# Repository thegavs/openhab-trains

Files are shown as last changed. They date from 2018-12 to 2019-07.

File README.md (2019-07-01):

# openhab-trains
Openhab-trains.  Combining the power of home automation systems and cheap arduinos to provide open source modules for running model trains.

Designed for Garden railways where dcc running over tracks proves problematic but will work with smaller scales.  The wifi modules have been 
tested at over 200 feet (60 metres) both inside and outside.
All modules are designed to run off 12v stepped down to 5v on board.   Most modules could also be modified to run on battery power.

Using the home automation system allows for complex rules to be set up, allowing electronic interlocking to be used for route setting. 

The Aim for this project is for people to be able to build simple cheap modules to control their layout and develop and add other modules 
to expand the system.

The core of the system is Openhab2 running on a Raspberry Pi. 

https://www.openhab.org/

Openhab is open source and free to use.

For ease of install I suggest using Openhabian.

https://www.openhab.org/docs/installation/openhabian.html

The modules are arduinos

https://www.arduino.cc/

I suggest using the nodemcu exp8266 or esp32 modules as they are inexpensive and powerful.

Video of first two modules in action.

https://youtu.be/3NVWC1UaGtM

**Modules published.**

Levers - reads the position of levers and transmits value to server.

signal - moves two semaphore signals.

points - moves 3 points.

relay - activates 2 relays

**Modules in development.**

ground signal - for two ground signals.

Brushless - allows control of brushless motors

**Install guides**

A guide to installing openhab server is in the openhab/install directory.

**Arduino modules**

Each module has its own directory with the code, wiring diagrams and component lists.

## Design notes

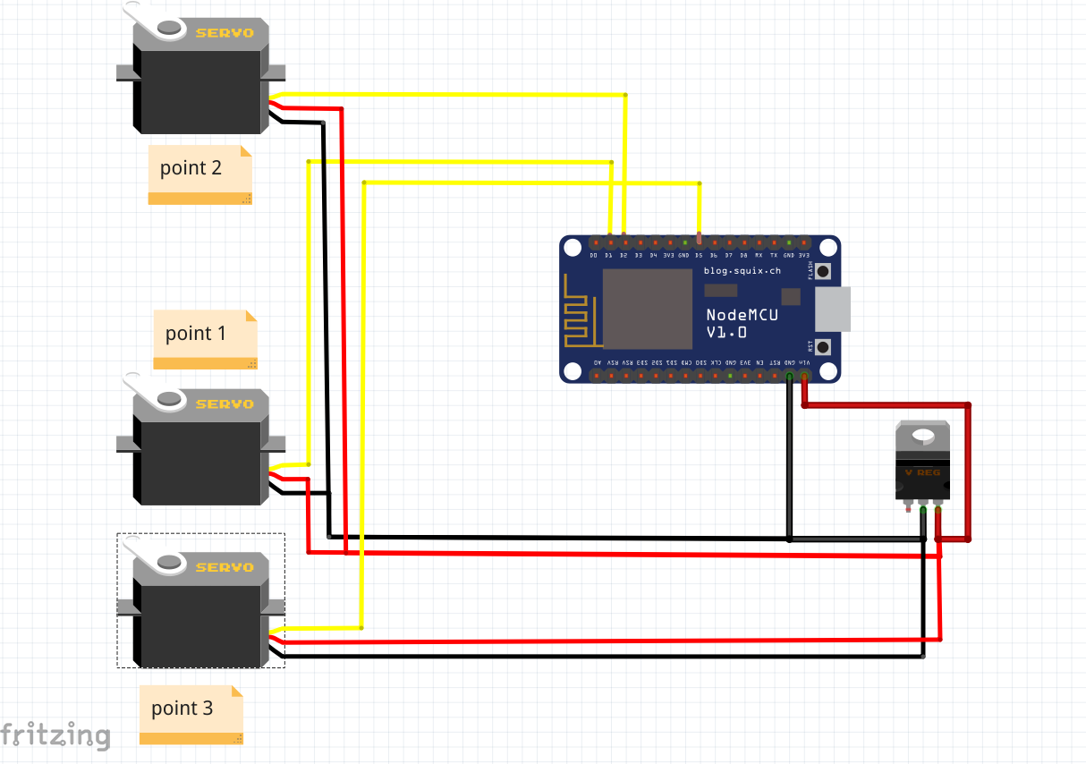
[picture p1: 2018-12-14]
arduino modules/points/points schematic.png

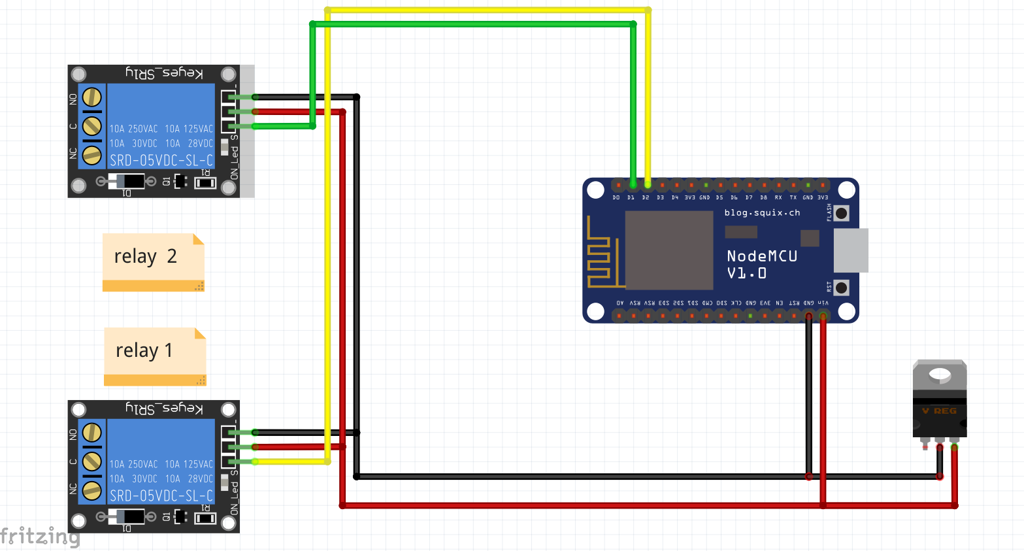
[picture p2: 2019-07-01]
arduino modules/relay/relay schematic.png

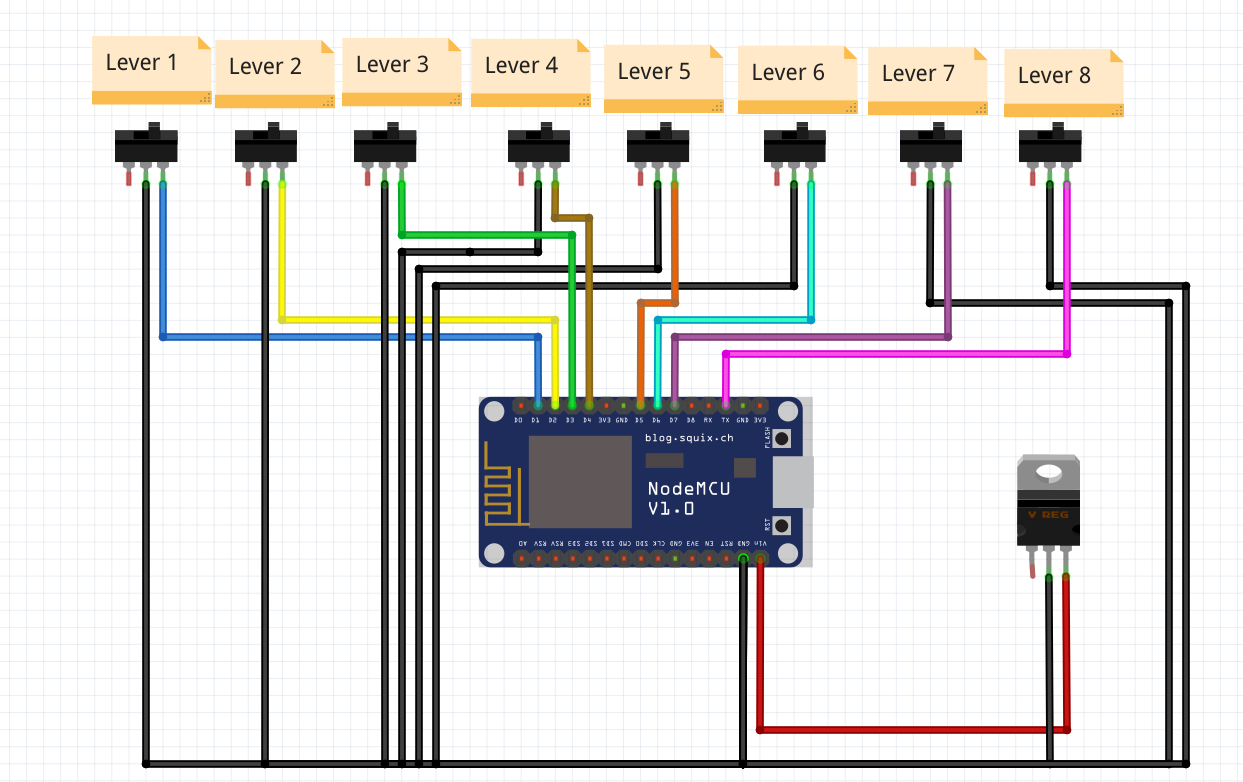
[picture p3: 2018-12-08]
arduino modules/signal levers/levers/levers_schematic.png

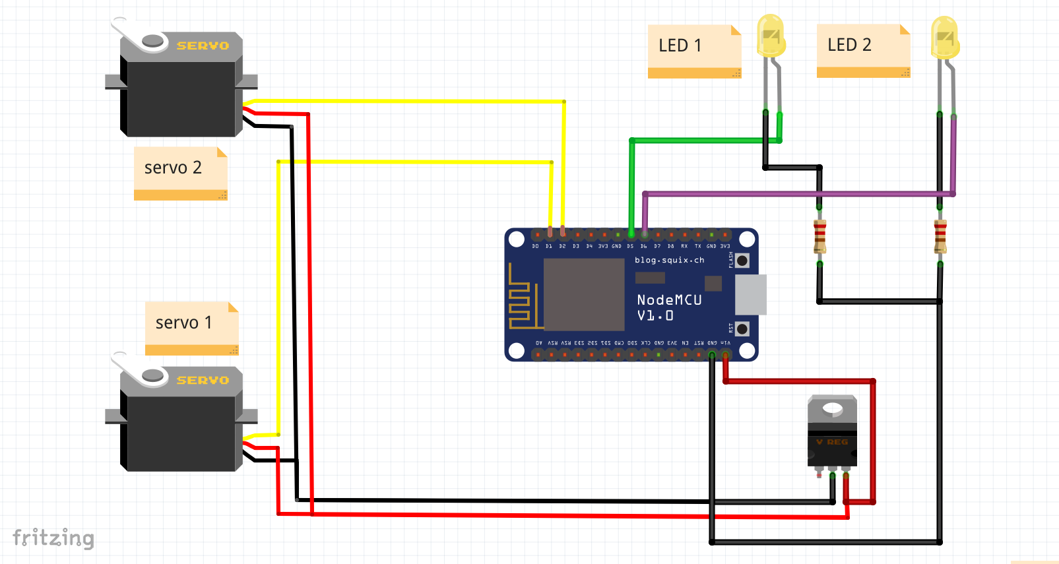
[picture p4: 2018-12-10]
arduino modules/signals/signal/signal schematic.png

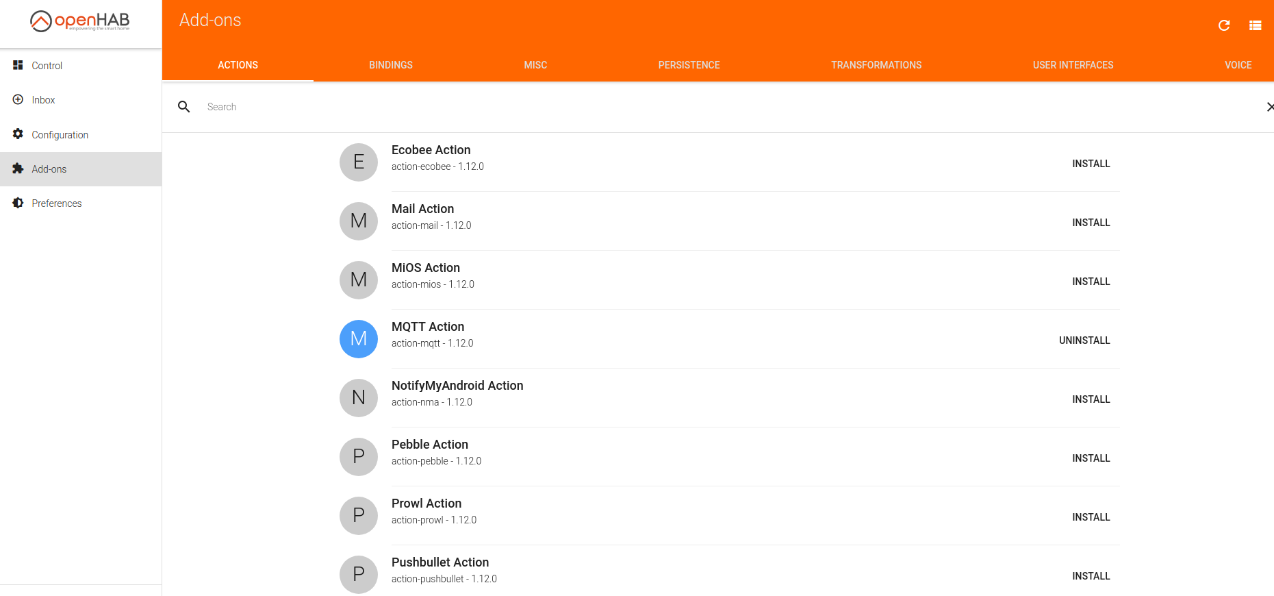
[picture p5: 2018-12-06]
arduino modules/signal levers/levers/MQTT action.png

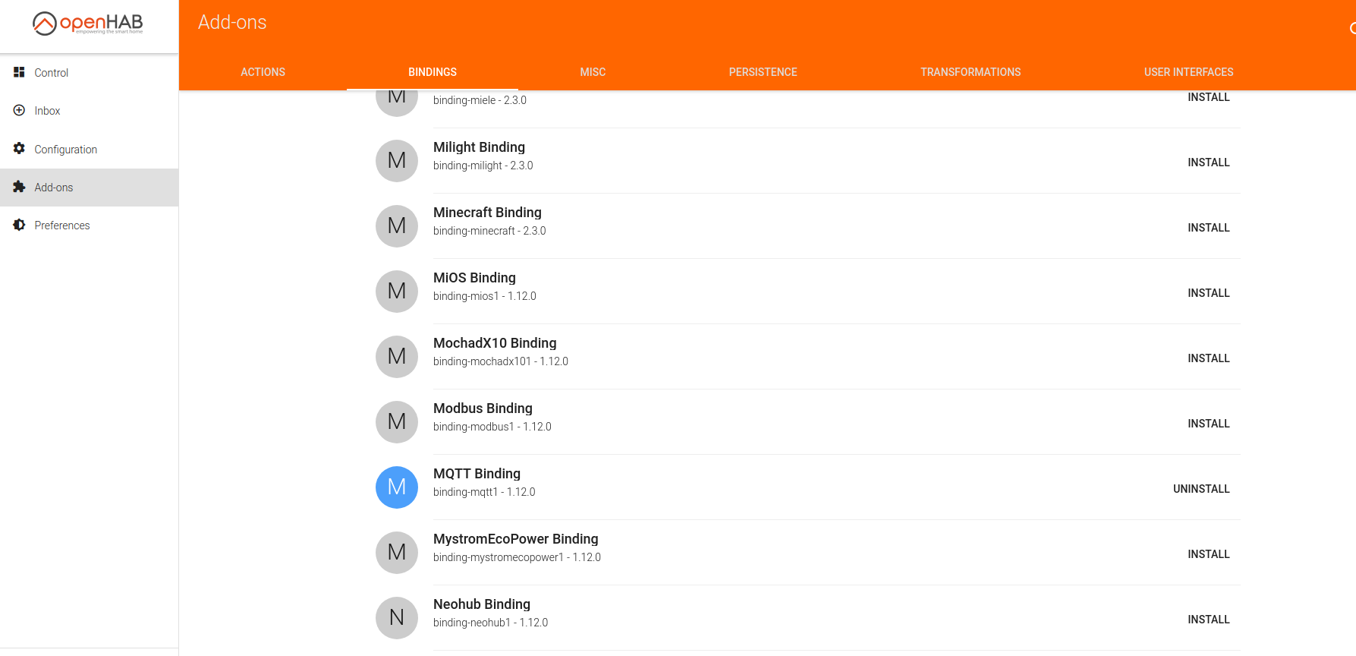
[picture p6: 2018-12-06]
arduino modules/signal levers/levers/MQTT binding.png

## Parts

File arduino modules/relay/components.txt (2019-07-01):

levers

This is a list of suggested components with links and costs.  I have no affiliation with the links other than a happy customer.

nodemcu (arduino)
https://www.ebay.co.uk/itm/NodeMcu-Lua-V3-ESP8266-CH340G-ESP-12E-WIFI-Lua-Internet-Development-Board-Module-/291968023031
cost from £2.36

voltage regulator 5v
https://www.bitsbox.co.uk/index.php?main_page=product_info&cPath=140_171&products_id=1306
cost £0.37

stripboard (will make multipule modules)
https://www.bitsbox.co.uk/index.php?main_page=product_info&cPath=238_244&products_id=1858
£2.80

assortied wire (will make multipule modules)
https://www.bitsbox.co.uk/index.php?main_page=product_info&cPath=200_201&products_id=2167
£1.88

15 way connector x 2
https://www.bitsbox.co.uk/index.php?main_page=product_info&cPath=225_230&products_id=2879
£0.68

5v relay x2
https://www.ebay.co.uk/itm/5V-12V-or-24V-1-2-4-8-16-Channel-Relay-Module-Arduino-PI-ARM-AVR-DSP-PIC-/262722739443
£2.75

Total cost around £15 the wire and strip board will do several modules cost ignoring these is around £6.16 per module.

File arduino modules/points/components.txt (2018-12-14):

levers

This is a list of suggested components with links and costs.  I have no affiliation with the links other than a happy customer.

nodemcu (arduino)
https://www.ebay.co.uk/itm/NodeMcu-Lua-V3-ESP8266-CH340G-ESP-12E-WIFI-Lua-Internet-Development-Board-Module-/291968023031
cost from £2.36

voltage regulator 5v
https://www.bitsbox.co.uk/index.php?main_page=product_info&cPath=140_171&products_id=1306
cost £0.37

stripboard (will make multipule modules)
https://www.bitsbox.co.uk/index.php?main_page=product_info&cPath=238_244&products_id=1858
£2.80

3 way JYK connectors female x 3
https://www.bitsbox.co.uk/index.php?main_page=product_info&cPath=225_339&products_id=2796
£0.27

3 way JYK connectors male x 3
https://www.bitsbox.co.uk/index.php?main_page=product_info&cPath=225_339&products_id=2797
0.50

crimp connectors x10
https://www.bitsbox.co.uk/index.php?main_page=product_info&cPath=225_339&products_id=2793
£0.70

assortied wire (will make multipule modules)
https://www.bitsbox.co.uk/index.php?main_page=product_info&cPath=200_201&products_id=2167
£1.88

15 way connector x 2
https://www.bitsbox.co.uk/index.php?main_page=product_info&cPath=225_230&products_id=2879
£0.68

Servos x3
https://www.ebay.co.uk/
£7.77

Total cost around £17 the wire and strip board will do several modules cost ignoring these is around £12.65 per module.

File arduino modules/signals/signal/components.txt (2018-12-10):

levers

This is a list of suggested components with links and costs.  I have no affiliation with the links other than a happy customer.

nodemcu (arduino)
https://www.ebay.co.uk/itm/NodeMcu-Lua-V3-ESP8266-CH340G-ESP-12E-WIFI-Lua-Internet-Development-Board-Module-/291968023031
cost from £2.36

voltage regulator 5v
https://www.bitsbox.co.uk/index.php?main_page=product_info&cPath=140_171&products_id=1306
cost £0.37

stripboard (will make multipule modules)
https://www.bitsbox.co.uk/index.php?main_page=product_info&cPath=238_244&products_id=1858
£2.80

connectors male x2
https://www.bitsbox.co.uk/index.php?main_page=product_info&cPath=225_339&products_id=2794
£0.18

connectors female x 2
https://www.bitsbox.co.uk/index.php?main_page=product_info&cPath=225_339&products_id=2792
£0.14

3 way JYK connectors female x 2
https://www.bitsbox.co.uk/index.php?main_page=product_info&cPath=225_339&products_id=2796
£0.18

3 way JYK connectors male x 2
https://www.bitsbox.co.uk/index.php?main_page=product_info&cPath=225_339&products_id=2797
0.32

crimp connectors x10
https://www.bitsbox.co.uk/index.php?main_page=product_info&cPath=225_339&products_id=2793
£0.70

assortied wire (will make multipule modules)
https://www.bitsbox.co.uk/index.php?main_page=product_info&cPath=200_201&products_id=2167
£1.88

15 way connector x 2
https://www.bitsbox.co.uk/index.php?main_page=product_info&cPath=225_230&products_id=2879
£0.68

LED x2
https://www.bitsbox.co.uk/index.php?main_page=product_info&cPath=172_176&products_id=1340
£0.20

220ohm resistor x 2
https://www.bitsbox.co.uk/index.php?main_page=product_info&cPath=83_84_85&products_id=437
£0.14

Servos x2
https://www.ebay.co.uk/itm/Tower-Pro-SG-90-SG90-9g-Micro-Servo-For-Car-Helicopter-Plane-Boat-New-UK-Seller/201515155582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
£5.18

Total cost around £15 the wire and strip board will do several modules cost ignoring these is around £10.45 per module.

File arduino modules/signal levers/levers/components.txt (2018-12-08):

levers

This is a list of suggested components with links and costs.  I have no affiliation with the links other than a happy customer.

nodemcu (arduino)
https://www.ebay.co.uk/itm/NodeMcu-Lua-V3-ESP8266-CH340G-ESP-12E-WIFI-Lua-Internet-Development-Board-Module-/291968023031
cost from £2.36

voltage regulator 5v
https://www.bitsbox.co.uk/index.php?main_page=product_info&cPath=140_171&products_id=1306
cost £0.37

stripboard (will make multipule modules)
https://www.bitsbox.co.uk/index.php?main_page=product_info&cPath=238_244&products_id=1858
£2.80

connectors male x8
https://www.bitsbox.co.uk/index.php?main_page=product_info&cPath=225_339&products_id=2794
£0.72

connectors female x 8
https://www.bitsbox.co.uk/index.php?main_page=product_info&cPath=225_339&products_id=2792
£0.56

crimp connectors x16
https://www.bitsbox.co.uk/index.php?main_page=product_info&cPath=225_339&products_id=2793
£0.64

assortied wire (will make multipule modules)
https://www.bitsbox.co.uk/index.php?main_page=product_info&cPath=200_201&products_id=2167
£1.88

15 way connector x 2
https://www.bitsbox.co.uk/index.php?main_page=product_info&cPath=225_230&products_id=2879
£0.68

Total cost around £10 the wire and strip board will do several modules cost ignoring these is around £5.33 per lever module.

These costs do not account for switches or levers as these will be personal preferences.

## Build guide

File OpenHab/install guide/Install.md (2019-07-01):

# Openhab install guide.

##**Introduction**

Openhab is an open source home automation system that can run on different hardware platforms.
I recommend using a [Raspberry Pi](https://www.raspberrypi.org/products/raspberry-pi-3-model-b-plus/).

These are simple but powerful tiny computers, that dont take much power.  

More information on openhab is available [here](https://www.openhab.org/) 

Below is a guide to install OpenHab on a raspberry pi.   All links are correct as of 21 dec 2018.

##**Openhabian**

[Openhabian](https://www.openhab.org/docs/installation/openhabian.html)  is a port of OpenHab that is designed for ease of installation on a Raspberry Pi.  Below is a step by step guide to installation.  
If links are out of date please contact me.

**1. Download Openhabian**

The Github page for Openhabian will have the latests releases [here](https://github.com/openhab/openhabian/releases) 

The latest RaspBerry Pi image is [here](https://bintray.com/openhab/bin/download_file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) This is a large download at
circa 255Mb.  The downloaded file needs to be written to the micro SD card that came with the Raspberry Pi.
As it is an image of a disk it needs to be extracted then written, various tools exist to do this I suggest using etcher.

**2. Etcher**

Etcher is a tool to write disk images to SD cards, it is available [here](https://www.balena.io/etcher/).
Once Etcher is installed simply select the image file you downloaded, then select the drive containing the 
Micro SD card then press Flash.

This will extract the files and check them.

**3. Update wifi details**

If you plan to use wifi on the raspberry pi you will need to update the wifi credentials.  If not move to step 4.

Access the first SD card partition from the file explorer of your choice (e.g. Windows file explorer)
Open the file openhabian.conf in a text editor
Uncomment and fill in wifi_ssid="My Wi-Fi SSID" and wifi_psk="password123"

This adds your wifi details

**4. Start install.**

Unmount the micro SD card then insert into the Pi.    The system is designed to run "headless" i.e no monitor, but a monitor can be plugged into the HDMI port.

Put the micro SD card into the pi and power on, if you skipped step 3 plug in the network cable first.   Grab a beer/tea and come back in an hour.

Note that if the wifi fails try the following.

Full steps below:

Flash fresh openHABian image to SD card (openhabianpi-raspbian-201804031720-gitdba76f6-crc9e93c3eb.img.xz)
Boot 3B+ from flashed SD, observe network error
Login on local shell using openhabian/openhabian
sudo raspi-config - set Network SSID, Passphrase, and WiFi Country
reboot

** 5. Connect to server**

In a web browser connect to http://ipaddress:8080 the first time you connect you should see a screen asking you to select "simple standard expert demo"  select the expert option then you should see various screens.

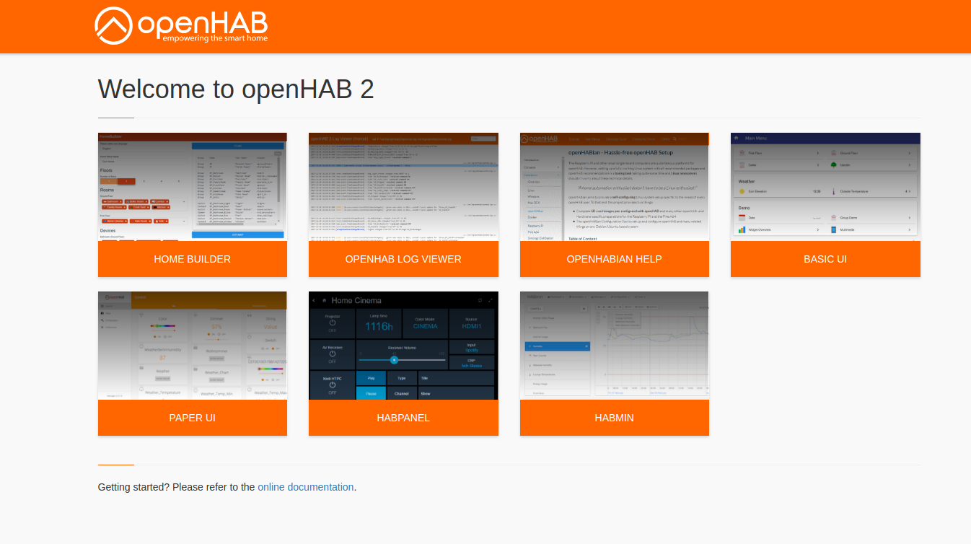
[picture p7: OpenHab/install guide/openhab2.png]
start screen


PaperUI is used to configure the server.

connecting to http://ipaddress:9001 will show you the log file.

Using filemanger on your PC you should be able to connect to a network drive with a username and password
of openhabian  this will allow you to change the configuration files.

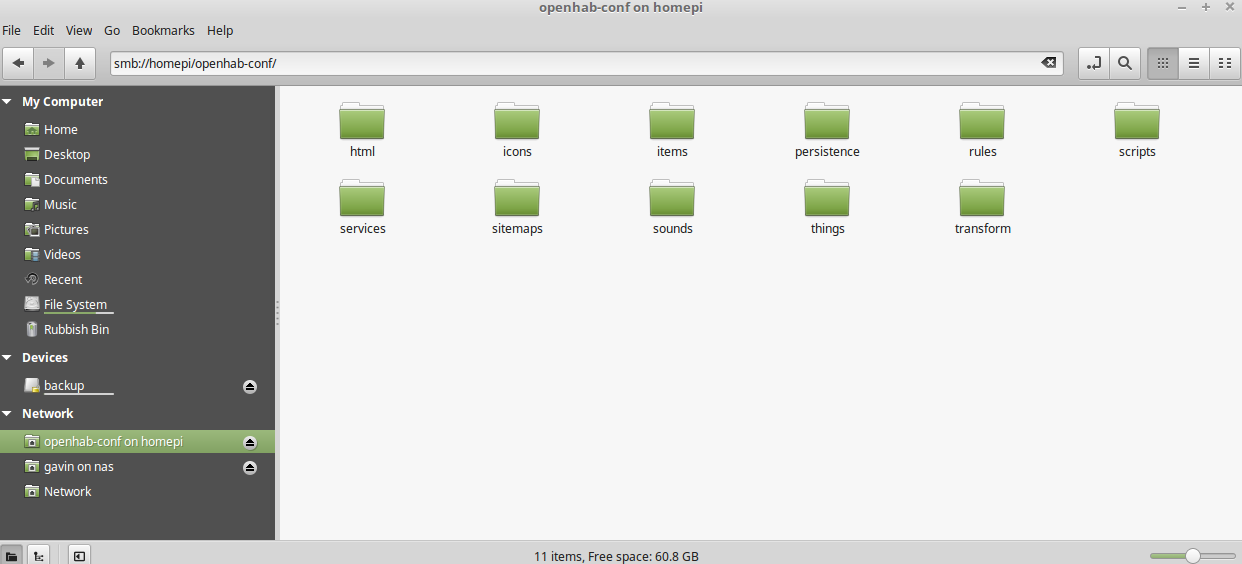
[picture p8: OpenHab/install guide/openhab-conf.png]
openhab file system


Also use ssh in a command line to connect to the server username and password again openhabian.  (For information on ssh see [ssh.md](./ssh.md) )

then run "sudo openhabian-config"  this then starts a configuration program.

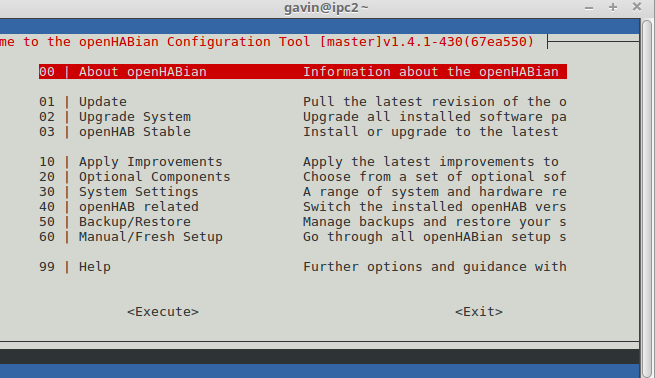
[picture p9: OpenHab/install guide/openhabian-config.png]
open hab config


**6. update system**

In the openhabian-config program select the first option (01) to down load the updates to the system.  

Then the second option (02) to install the updates, this may take some time.

Then go to the "Apply latest improvements" menu (10)

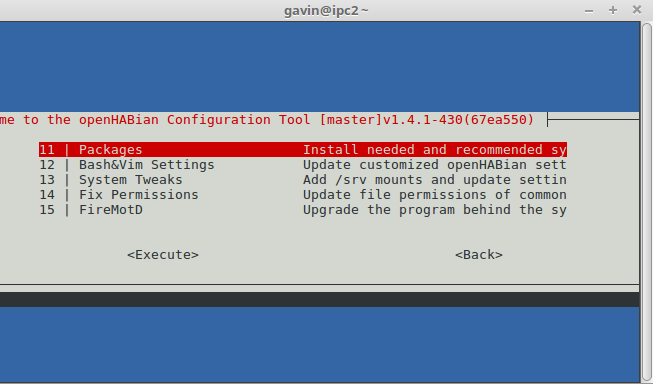
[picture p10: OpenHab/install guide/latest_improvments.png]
latest improvments


Click on each item to change the system.

**7. Static ip address**

The ip address of the raspberry pi needs to be a fixed address so it does not change every time it is rebooted.  To do this log onto your route and reserve the ip address in the DHCP section.  Details of how to do this will vary according to router but information on how to to do this can be found online.

**8. Install MQTT**

Still in openhab-config go to the "Optional Components" section in the main menu.

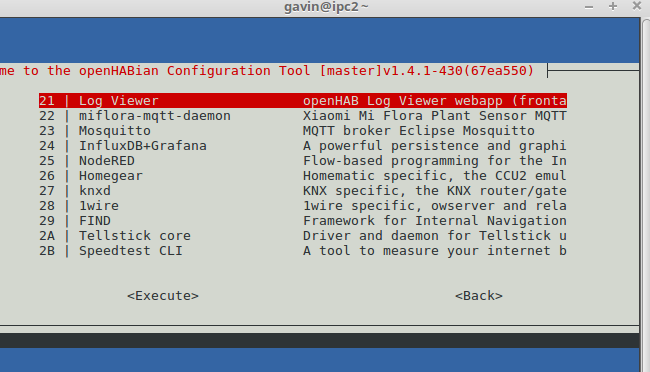
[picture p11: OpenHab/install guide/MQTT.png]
MQTT


Click on (23) Mosquitto to install the MQTT server, you can select all the default options.

**9. Install bindings**

Openhab uses a system of optional bindings to enable the system to work.   These bindings are continuously updated enabling the server to connect to and control differing devices.

Openhab-trains currently needs 4 bindings to be installed to work.

In a web browser connect to the server http//ipaddress:8080. 

Select the paper UI panel and then configuration - system and ensure
"include legacy 1.x bindings" is set on.

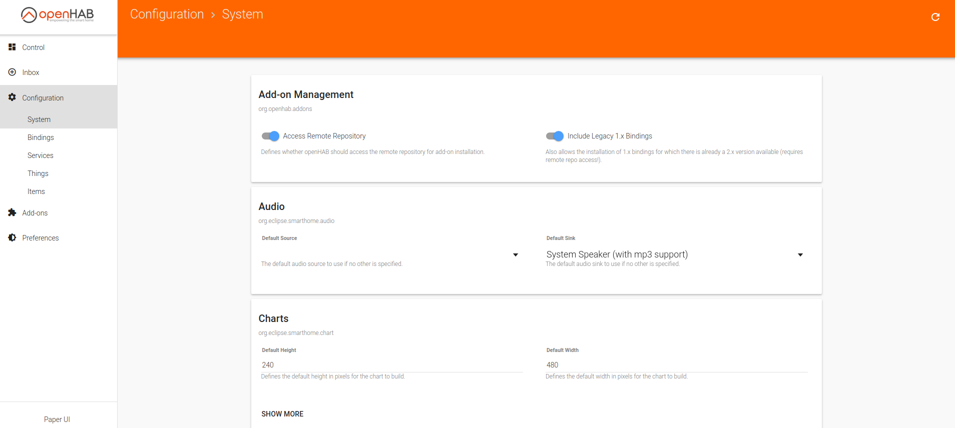
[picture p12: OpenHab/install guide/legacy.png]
legacy bindings


Select the paper UI panel and then addons - bindings.  Find the MQTT binding and install it.

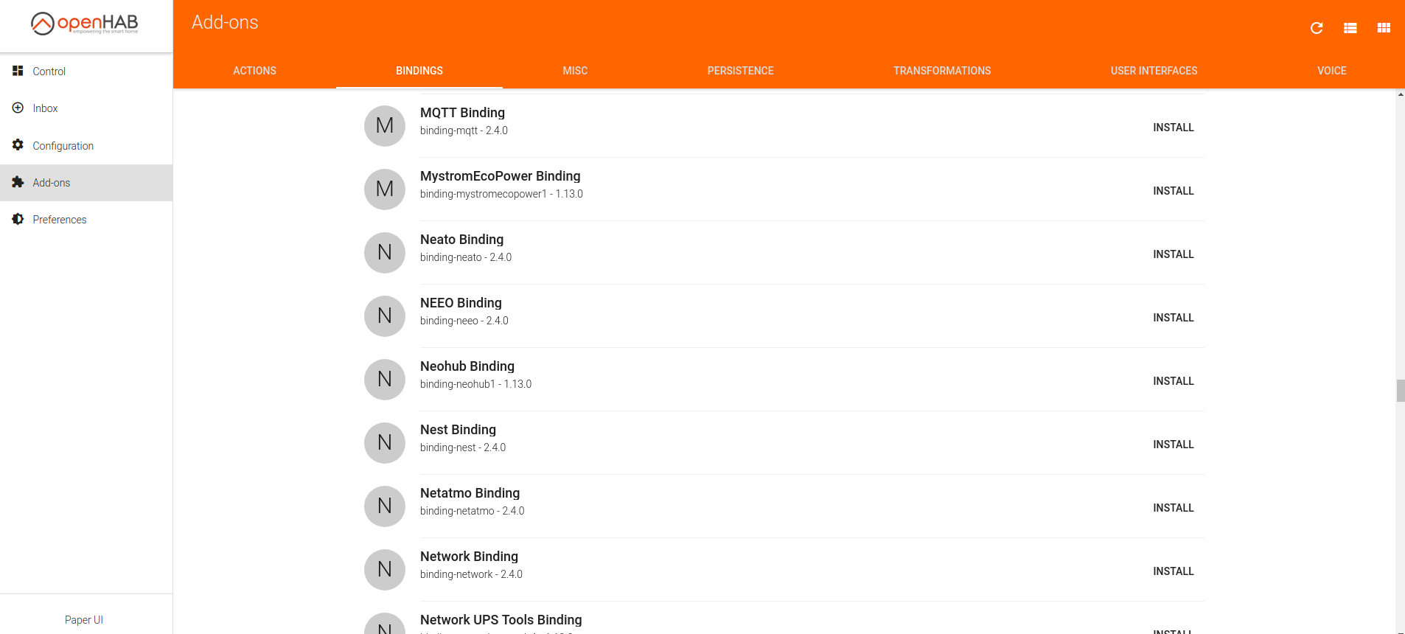
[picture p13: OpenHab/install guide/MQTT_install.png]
MQTT install


Then still in paper UI go to addons - persistence and install the MQTT Persistence binding.

Next is the MQTT action binding which is in addons - actions.  Install the MQTT action binding.

Finally the MAP Transformation which is in addons - transformations.
Install the MAP transformation.

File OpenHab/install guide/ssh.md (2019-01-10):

**SSH**

ssh is a secure way of connecting to computers, it is used to connect initially to the raspberry pi to set up.  It is installed as standard on some operating systems and needs to be installed on others.

**Linux**

Installed as standard

**MacOS** 

Installed as standard.

**Windows 10**

Installed but not enabled.  Use the following link to find a guide to enable.

[SSH Windows 10](https://www.howtogeek.com/336775/how-to-enable-and-use-windows-10s-built-in-ssh-commands/) 

**Windows pre 10**

For windows versions pre 10 you will need to install ssh.  There are various versions available.  Putty has been used successfully to install openhab-trains.

[Putty](https://www.ssh.com/ssh/putty/windows/?fbclid=IwAR2_Yr7LfqBh2UmIHm2ovabPFYl6WIbBi0YM_R8iUpg17i1exZ88ewV8tC0) 

**phones and tablets**

ssh can be installed on android and apple phones and tablets.   Connectbot has been used to successfully install openhab-trains.  This will be available in your app store.

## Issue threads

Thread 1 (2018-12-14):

Wrong pin in signal. Ino

thegavs, 2018-12-14:
Suspect pin numbers are wrong in signal. Ino

thegavs, 2018-12-14:
Arudino pins were right but nodemcu pins the wrong way around.  Corrected now.

Will be updated in next comit.

Closed 2018-12-14.

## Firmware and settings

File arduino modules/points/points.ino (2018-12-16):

// ************************************************************************* 
// **  a module from openhab-trains to work 3 point servos                **
// **                                                                     **
// **                                                                     **
// **  https://github.com/thegavs/openhab-trains                          **
// **                                                                     **
// **  Change "point_1,2 & 3" to something that makes sense to you.       **
// **                                                                     **
// **  Change SSID, PASSWORD to your wifi network.                        **
// **                                                                     **
// **  Change IPADDRESS to the ip address of the MQTT server.             **
// **  if only using one network the SSID2 and 3 can be left as is.       **
// **                                                                     **
// **  Look for //**changeme**//                                          **
// **                                                                     **
// **  The point start and end position can be changed in openhab rules   **
// **                                                                     **
// **  v1.0 initial realease.                                             **
// ************************************************************************* 

#include <EEPROM.h>
#include <ESP8266WiFi.h>
#include <PubSubClient.h>
#include <Servo.h>


// DEFINE HERE THE KNOWN NETWORKS
const char* KNOWN_SSID[] = {"SSID1", "SSID2", "SSID3"}; //**changeme**//
const char* KNOWN_PASSWORD[] = {"PASSWORD1", "PASSWORD2", "PASSWORD3"}; //**changeme**//
const char* KNOWN_MQTT[] = {"IPADDRESS1", "IPADDRESS2", "IPADDRESS2"}; //**changeme**//
 
const int   KNOWN_SSID_COUNT = sizeof(KNOWN_SSID) / sizeof(KNOWN_SSID[0]); // number of known networks

char* topic_1 = "point_1"; //**changeme**//
char* topic_2 = "point_2"; //**changeme**//
char* topic_3 = "point_3"; //**changeme**//
 
WiFiClient espClient;
PubSubClient client(espClient);
 
String message;
char* receivedChar;

char message_buff[10];
int pos = 0;    // variable to store the servo position


int on_off;
int low;
int high;
String temp;

Servo point1;
Servo point2;
Servo point3;


void callback(char* topic, byte* payload, unsigned int length) {
 Serial.print("Message arrived [");
 Serial.print(topic);
 Serial.print("] ");

 for (int i=0;i<length;i++) 
 {
    char receivedChar = (char)payload[i];
    Serial.print(receivedChar);
    message = message + String(receivedChar);
  }
  //String led_char = String(receivedChar);

 // Serial.println();
  //Serial.print(topic);
 // Serial.print(message);
 // Serial.println();

  temp = message.substring(0,1);
  on_off = temp.toInt();
  Serial.println(on_off);

  temp = message.substring(2,5);
  low = temp.toInt();
  Serial.println(low);

  temp = message.substring(6,9);
  high = temp.toInt();
  Serial.println(high);

  
  if (strcmp(topic,topic_1) == 0) 
    {
      Serial.print("point 1");
      Serial.println(message);
      if (on_off == 0)
      {
        Serial.print("inside 0");
        Serial.println();
        for (pos = low; pos <= high; pos += 1)   
        { // goes from 0 degrees to 180 degrees
                                  // in steps of 1 degree
          point1.write(pos);              // tell servo to go to position in variable 'pos'
          Serial.println(pos);
          delay(15);  
        }

      }
      else
      {
        Serial.print(high);
        for (pos = high; pos >= low; pos -= 1) 
        { // goes from 180 degrees to 0 degrees
          point1.write(pos);              // tell servo to go to position in variable 'pos'
          delay(15);                       // waits 15ms for the servo to reach the position
        }
      }
    }
  if (strcmp(topic, topic_2) == 0) 
   {
    if (on_off == 0) // off or up or danger
      {
        Serial.print("inside 0");
        Serial.println();
        for (pos = low; pos <= high; pos += 1)   
        { // goes from 0 degrees to 180 degrees
                                  // in steps of 1 degree
          point2.write(pos);              // tell servo to go to position in variable 'pos'
          delay(15);  
        }
        
      }
      else // on or down or go or green
      {
        for (pos = high; pos >= low; pos -= 1) 
        { // goes from 180 degrees to 0 degrees
          point2.write(pos);              // tell servo to go to position in variable 'pos'
          delay(15);                       // waits 15ms for the servo to reach the position
        }
      }

   

   }

  if (strcmp(topic, topic_3) == 0) 
   {
    if (on_off == 0) // off or up or danger
      {
        Serial.print("inside 0");
        Serial.println();
        for (pos = low; pos <= high; pos += 1)   
        { // goes from 0 degrees to 180 degrees
                                  // in steps of 1 degree
          point3.write(pos);              // tell servo to go to position in variable 'pos'
          delay(15);  
        }
        
      }
      else // on or down or go or green
      {
        for (pos = high; pos >= low; pos -= 1) 
        { // goes from 180 degrees to 0 degrees
          point3.write(pos);              // tell servo to go to position in variable 'pos'
          delay(15);                       // waits 15ms for the servo to reach the position
        }
      }

   

   }   
   message = "";

}
 
 
void reconnect() {
 // Loop until we're reconnected
 while (!client.connected()) {
 Serial.print("Attempting MQTT connection...");
 // Attempt to connect
 if (client.connect("ESP8266 Client")) {
  Serial.println("connected");
  // ... and subscribe to topic
  client.subscribe(topic_1);
  client.subscribe(topic_2);
  client.subscribe(topic_3);
 } else {
  Serial.print("failed, rc=");
  Serial.print(client.state());
  Serial.println(" try again in 5 seconds");
  // Wait 5 seconds before retrying
  delay(5000);
  }
 }
}



 
void setup()
{
  boolean wifiFound = false;
  int i, n;

  Serial.begin(115200);

  // ----------------------------------------------------------------
  // Set WiFi to station mode and disconnect from an AP if it was previously connected
  // ----------------------------------------------------------------
  WiFi.mode(WIFI_STA);
  WiFi.disconnect();
  delay(100);
  Serial.println("Setup done");

  // ----------------------------------------------------------------
  // WiFi.scanNetworks will return the number of networks found
  // ----------------------------------------------------------------
  Serial.println(F("scan start"));
  int nbVisibleNetworks = WiFi.scanNetworks();
  Serial.println(F("scan done"));
  if (nbVisibleNetworks == 0) {
    Serial.println(F("no networks found. Reset to try again"));
    while (true); // no need to go further, hang in there, will auto launch the Soft WDT reset
  }

  // ----------------------------------------------------------------
  // if you arrive here at least some networks are visible
  // ----------------------------------------------------------------
  Serial.print(nbVisibleNetworks);
  Serial.println(" network(s) found");

  // ----------------------------------------------------------------
  // check if we recognize one by comparing the visible networks
  // one by one with our list of known networks
  // ----------------------------------------------------------------
  for (i = 0; i < nbVisibleNetworks; ++i) {
    Serial.println(WiFi.SSID(i)); // Print current SSID
    for (n = 0; n < KNOWN_SSID_COUNT; n++) { // walk through the list of known SSID and check for a match
      if (strcmp(KNOWN_SSID[n], WiFi.SSID(i).c_str())) {
        Serial.print(F("\tNot matching "));
        Serial.println(KNOWN_SSID[n]);
      } else { // we got a match
        wifiFound = true;
        break; // n is the network index we found
      }
    } // end for each known wifi SSID
    if (wifiFound) break; // break from the "for each visible network" loop
  } // end for each visible network

  if (!wifiFound) {
    Serial.println(F("no Known network identified. Reset to try again"));
    while (true); // no need to go further, hang in there, will auto launch the Soft WDT reset
  }

  // ----------------------------------------------------------------
  // if you arrive here you found 1 known SSID
  // ----------------------------------------------------------------
  Serial.print(F("\nConnecting to "));
  Serial.println(KNOWN_SSID[n]);

  // ----------------------------------------------------------------
  // We try to connect to the WiFi network we found
  // ----------------------------------------------------------------
  WiFi.begin(KNOWN_SSID[n], KNOWN_PASSWORD[n]);

  while (WiFi.status() != WL_CONNECTED) {
    delay(500);
    Serial.print(".");
  }
  Serial.println("");

  // ----------------------------------------------------------------
  // SUCCESS, you are connected to the known WiFi network
  // ----------------------------------------------------------------
  Serial.println(F("WiFi connected, your IP address is "));
  Serial.println(WiFi.localIP());
  Serial.println(KNOWN_MQTT[n]);
 
  client.setServer(KNOWN_MQTT[n], 1883);    // MQTT setup
  client.setCallback(callback);

  point1.attach(5); // D5 or D1 nodemcu
  point2.attach(4);   // D4 or D2 nodemcu
  point3.attach(14);  //D14 or D5 nodemcu


}
 
void loop()
{
 if (!client.connected()) {
  reconnect();
 }
 client.loop();
}

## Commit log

2018-12-08 adding lever module
    [levers.fzz]
2018-12-10 adding signal module
    [signal.fzz]
2018-12-14 adding point module
    [points.fzz]
2019-07-01 added relay module
    [relay.fzz]
